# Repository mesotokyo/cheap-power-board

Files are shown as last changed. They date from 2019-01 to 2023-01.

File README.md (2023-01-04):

Cheap Power Board - Power Supply Board for Eurorack Modular
===========================================================

Cheap, compact power supply board for Eurorack modular.

 * INPUT: DC 15V
 * OUTPUT: DC +12V, -12V, +5V

This schematic and PCB data uses mst-kicad-lib: https://github.com/mesotokyo/mst-kicad-lib

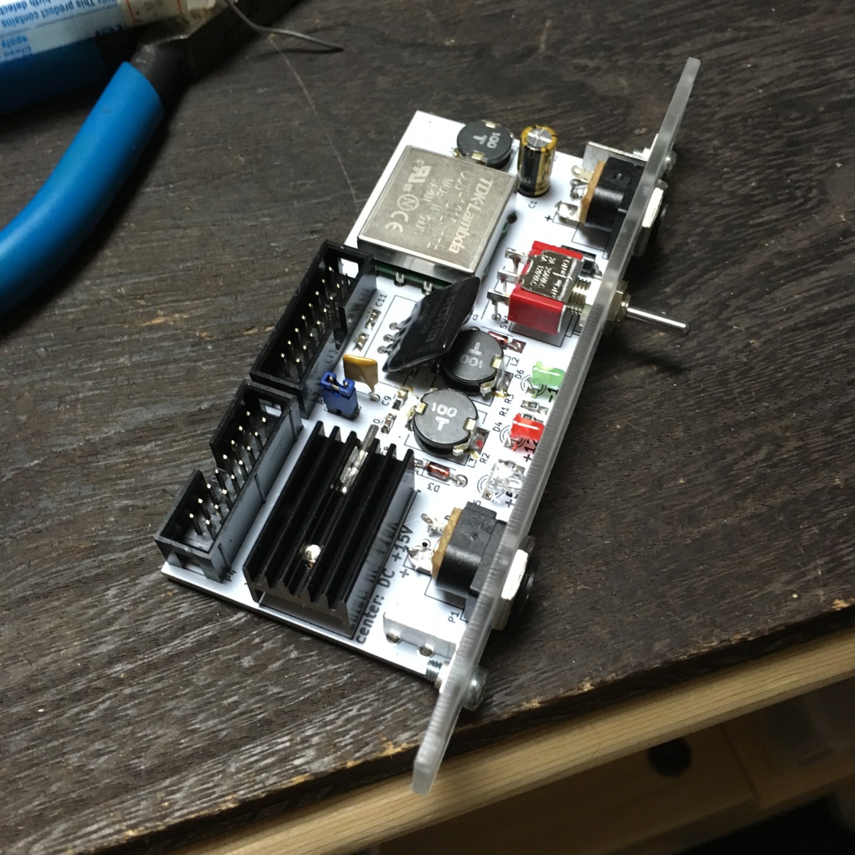
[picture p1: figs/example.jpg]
building example

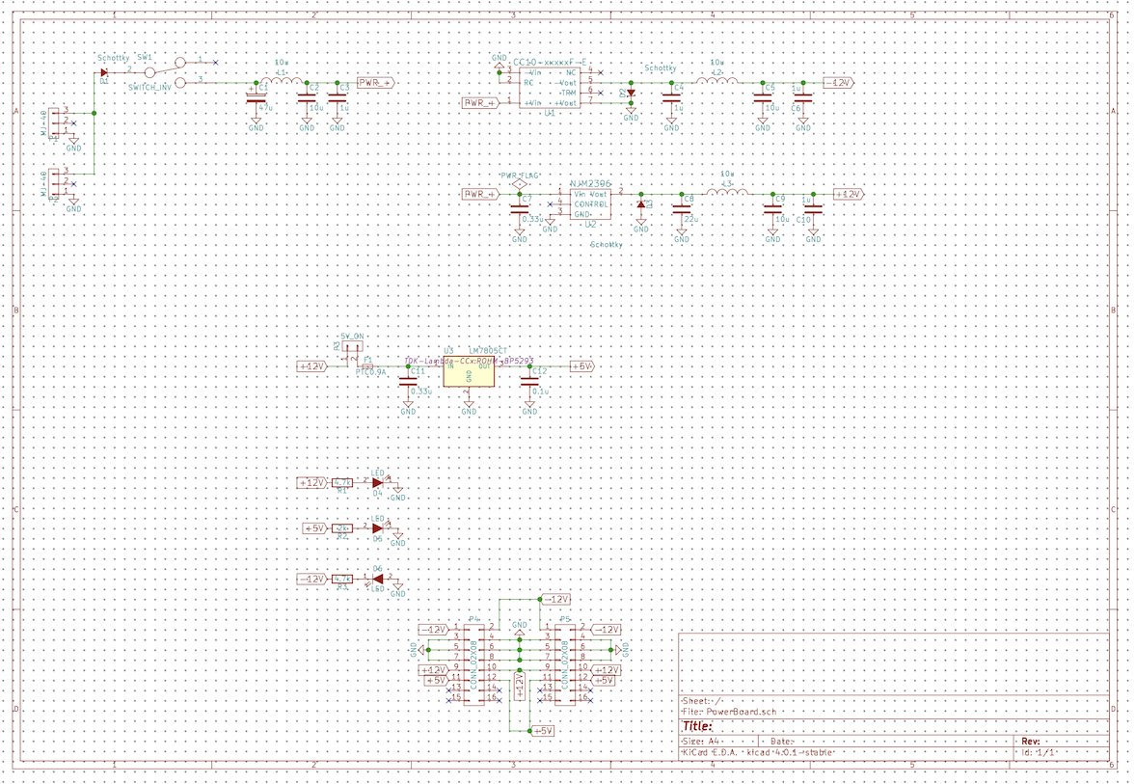
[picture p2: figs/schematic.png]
schematic image

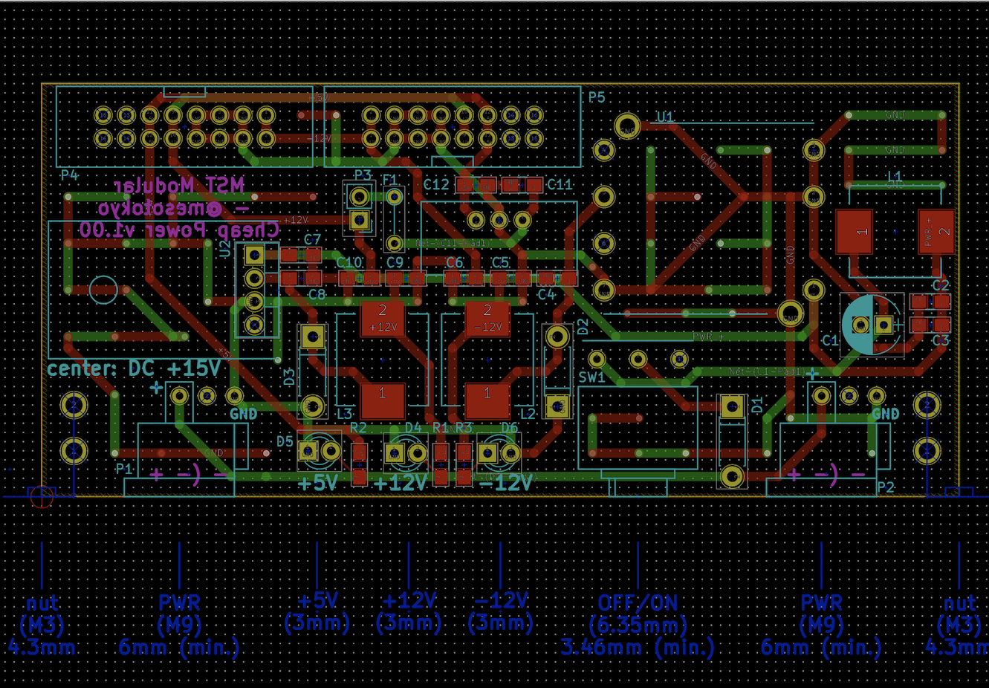
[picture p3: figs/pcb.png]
PCB image


## BOM

Please check [BOM.txt](BOM.txt).

## Note for assembly

 * U2: The Square pad is for pin 1.
 * It is recommended to use heatsink for U2.
 * The triple pads with rectangle near the center of the board is for U3 (right side of F1). The leftmost pad is for Vout.
   - If you use 7805 type voltage regulator, the leftmost pad is for pin 1.
 * The P3 is jumpmer pin. You can enable 5V output by shorting these pins.
 * The holes on each side can be used to mount the board. The hole spacing matches this PCB terminal [PCB-54L](https://akizukidenshi.com/catalog/g/gC-12218/) and [PCB-54R](https://akizukidenshi.com/catalog/g/gC-12219/).

## LICENSE

CC-BY 4.0 International

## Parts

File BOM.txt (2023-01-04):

Reference	Value	Footprint
C1	47u	Capacitors_ThroughHole:CP_Radial_D6.3mm_P2.50mm
C2	10u	Capacitors_SMD:C_0805_HandSoldering
C3	1u	Capacitors_SMD:C_0805_HandSoldering
C4	1u	Capacitors_SMD:C_0805_HandSoldering
C5	10u	Capacitors_SMD:C_0805_HandSoldering
C6	1u	Capacitors_SMD:C_0805_HandSoldering
C7	0.33u	Capacitors_SMD:C_0805_HandSoldering
C8	22u	Capacitors_SMD:C_0805_HandSoldering
C9	10u	Capacitors_SMD:C_0805_HandSoldering
C10	1u	Capacitors_SMD:C_0805_HandSoldering
C11	0.33u	Capacitors_SMD:C_0805_HandSoldering
C12	0.1u	Capacitors_SMD:C_0805_HandSoldering
D1	Schottky	Diodes_ThroughHole:D_DO-41_SOD81_P7.62mm_Horizontal
D2	Schottky	Diodes_ThroughHole:D_DO-41_SOD81_P7.62mm_Horizontal
D3	Schottky	Diodes_ThroughHole:D_DO-41_SOD81_P7.62mm_Horizontal
D4	LED	LEDs:LED_D3.0mm
D5	LED	LEDs:LED_D3.0mm
D6	LED	LEDs:LED_D3.0mm
F1	PTC(Fuse), 0.9A	Resistors_ThroughHole:R_Axial_DIN0204_L3.6mm_D1.6mm_P5.08mm_Vertical
L1	10u	INDUCTOR:TAIYO_YUDEN_NR10050
L2	10u	INDUCTOR:TAIYO_YUDEN_NR10050
L3	10u	INDUCTOR:TAIYO_YUDEN_NR10050
P1	MJ-40	BOX-HEADER:MJ-40
P2	MJ-40	BOX-HEADER:MJ-40
P3	5V_ON	Pin_Headers:Pin_Header_Straight_1x02_Pitch2.54mm
P4	CONN_02X08	BOX-HEADER:BOXHEADER-8x2
P5	CONN_02X08	BOX-HEADER:BOXHEADER-8x2
R1	4.7k	Resistors_SMD:R_0805_HandSoldering
R2	2k	Resistors_SMD:R_0805_HandSoldering
R3	4.7k	Resistors_SMD:R_0805_HandSoldering
SW1	SWITCH_INV	TOGGLE_SW:SW-1MS1
U1	CC10-1212SF-E	TDK-Lambda-CCx:CC6-1212SF-E
U2	NJM2396F12	TO_SOT_Packages_THT:TO-220-4_Vertical
U3	LM7805CT	TDK-Lambda-CCx:ROHM-BP5293

Note 1: It is recommended to use capaciters with a rated voltage of 16V or higher.
Note 2: Please use a diode with a rated voltage of 16V or higher and a rated current of 1A or higher. Also you can use normal diode instead of schottky diode D1.
Note 3: It is recommendedto use shottky diode with a rated voltage of 25V or higher for D2 and D3. 
Note 4: If you want to change the brightness of the LEDs, please change the value of the resistors R1, R2, R3.
Note 5: You can also use generic voltage regulator (5V), but through holes of the U3 are small, so it's better to check the pin size in advance.

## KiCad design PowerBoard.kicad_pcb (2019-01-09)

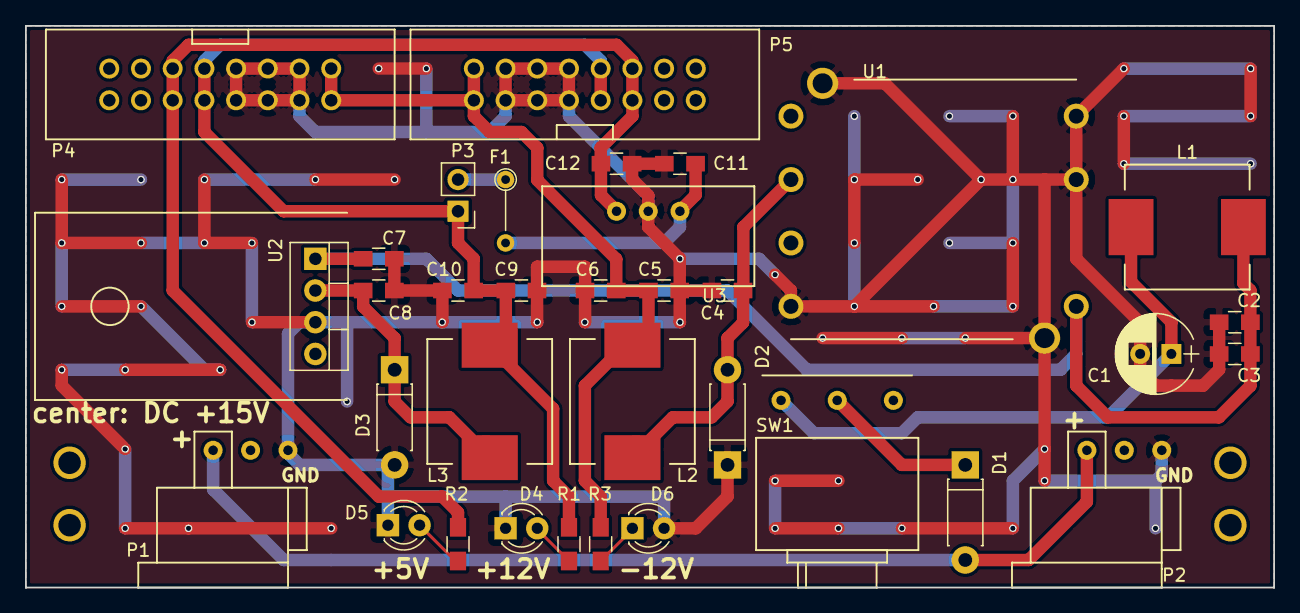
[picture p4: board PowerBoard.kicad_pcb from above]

Board: 2 copper layers, 100.0 x 45.0 mm, 34 parts (0 on the bottom side), 15 nets.

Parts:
C1: 47u; CP_Radial_D6.3mm_P2.50mm
C2, C5, C9: 10u; C_0805_HandSoldering
C3, C4, C6, C10: 1u; C_0805_HandSoldering
C7, C11: 0.33u; C_0805_HandSoldering
C8: 22u; C_0805_HandSoldering
C12: 0.1u; C_0805_HandSoldering
D1, D2, D3: Schottky; D_DO-41_SOD81_P7.62mm_Horizontal
D4, D5, D6: LED; LED_D3.0mm
F1: PTC0.9A; R_Axial_DIN0204_L3.6mm_D1.6mm_P5.08mm_Vertical
L1, L2, L3: 10u; TAIYO_YUDEN_NR10050
P1, P2: MJ-40
P3: 5V_ON; Pin_Header_Straight_1x02_Pitch2.54mm
P4, P5: CONN_02X08; BOXHEADER-8x2
R1, R3: 4.7k; R_0805_HandSoldering
R2: 2k; R_0805_HandSoldering
SW1: SWITCH_INV; SW-1MS1
U1: CC10-xxxxxF-E; CC6-xxxxxF-E
U2: NJM2396; TO-220-4_Vertical
U3: LM7805CT; ROHM-BP5293

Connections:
+5V: C12.1, P4.11, P4.12, P5.11, P5.12, R2.2, U3.3
+12V: C9.1, C10.2, L3.2, P3.1, P4.9, P4.10, P5.9, P5.10, R1.2
-12V: C5.1, C6.2, L2.2, P4.1, P4.2, P5.1, P5.2, R3.2
GND: C1.2, C2.2, C3.2, C4.2, C5.2, C6.1, C7.2, C8.2, C9.2, C10.1, C11.2, C12.2, D2.1, D3.2, D4.1, D5.1, D6.2, P1.1, P2.1, P4.3, P4.4, P4.5, P4.6, P4.7, P4.8, P5.3, P5.4, P5.5, P5.6, P5.7, P5.8, U1.2, U1.3, U1.7, U2.3, U3.2
unnamed: C1.1, L1.1, SW1.3
unnamed: C4.1, D2.2, L2.1, U1.5
unnamed: C8.1, D3.1, L3.1, U2.2
unnamed: C11.1, F1.2, U3.1
unnamed: D1.1, SW1.2
unnamed: D1.2, P1.3, P2.3
unnamed: D4.2, R1.1
unnamed: D5.2, R2.1
unnamed: D6.1, R3.1
unnamed: F1.1, P3.2
PWR_+: C2.1, C3.1, C7.1, L1.2, U1.1, U2.1
